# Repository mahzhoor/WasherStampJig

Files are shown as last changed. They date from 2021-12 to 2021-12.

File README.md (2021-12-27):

# WasherStampJig
DYI Printable 3D Template for Stamping Metal Washers - Cheap and secure Cold Storage for backing up your passwords and cryptocurrency seeds

v. 1.1

## The idea

To backup your sensitive data – stamp them on metal washers.  
This printable jig will allow you to align any letter stamps on any washers neatly.

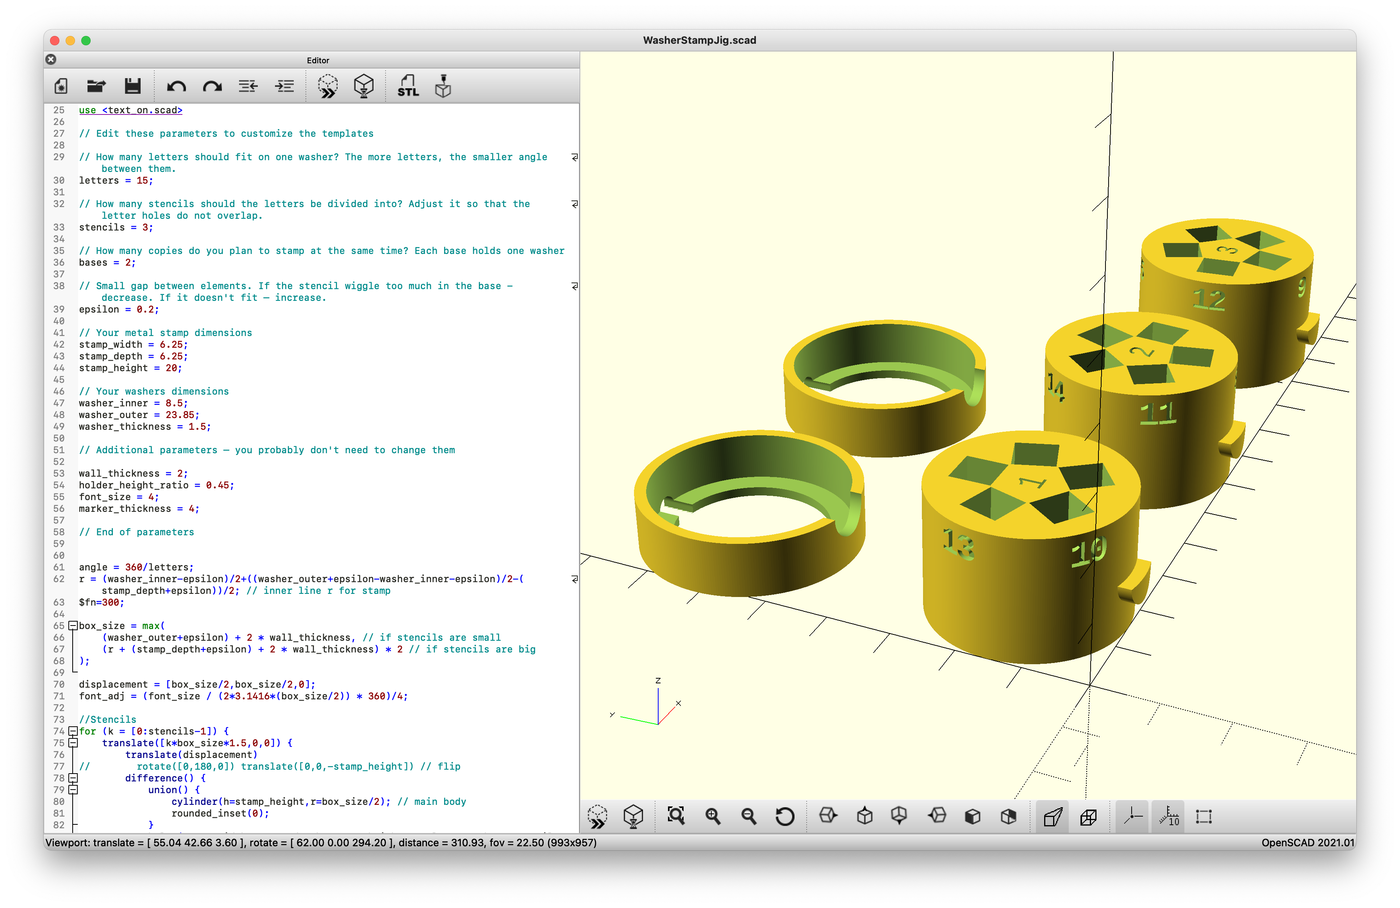
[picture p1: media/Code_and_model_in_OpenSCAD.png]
Code and 3D model in OpenSCAD software


Read more about the original idea of stamping washers: https://safu.ninja/  
Check out the [stress test/review](https://jlopp.github.io/metal-bitcoin-storage-reviews/reviews/safu-ninja/) and [comparison](https://jlopp.github.io/metal-bitcoin-storage-reviews/) to other solutions by Jameson Lopp.

## How to

### You'll need:
* Access to 3D printer 
* Metal stamps
* Metal washers
* Caliper
* Hammer
* Small anvil or any block/plate of metal
* Some tape - e.g. duct tape
* Marker pen

### Instructions:
1. Customize and generate the 3D template:
    1. Install [OpenSCAD](https://openscad.org/) software 
    1. Download and open the WasherStampJig.scad file
    1. Measure your washers and stamps
    1. Adjust the parameters to your needs – washer and stamp sizes, etc.
    1. Render the objects, generate STL file and print it in 3D
1. Prepare the base(s) – use two or more to create duplicates for backup purposes
    1. Put a piece of tape on flat surface
    1. Put the base on the tape so it stick from the bottom
    1. Put the washer in the hole in the base so it sticks to the tape
    1. Mark the washer side with a marker through the notch in the base side (so you can reposition it correctly in case it falls out in the middle of stamping)
1. Prepare the stencils:
    1. Write down all the words you wish to stamp in a table – put each word in a separate row, each letter in a separate column and number the columns
    1. Put the stamps for the first word in proper holes of the stencils - refer to the letter/column numbers in the table
1. Put the stencil in the base (so it sits on top of the washer) and hit the stamps with a hammer to stamp the letters – repeat for each stencil, base and word

## Why this?

### Customizability
You can easily adjust the jig to fit **any stamps** and any **any washers**. You can also adjust margins, height, font size etc.

### Usability and time savings
The design **saves you time** and makes it **easier** to create **multiple copies** of stamps.

Since the template for each stamp is broken into multiple stencils (to accomodate narrow angles between each stamp) – all of the letters of a word can be prepared in batch, at the same time.  
Then you can proceed to stamp all of them at once - on one or more washers (each taped to its own base).

This dramatically improves time needed to stamp multiple washers (in multiple copies) and reduces mistakes as compared to alternative solutions (which usually force you to stamp each letter separately).

Please see other implementations of the same idea to compare:
* [Blockmit Washer Jig](https://estudiobitcoin.com/fabrica-tu-billetera-fria-con-arandelas/)
* [Keytala Jig](https://www.hardwarewallet.it/en/keytala-jig/)

## Help needed

Contact me: mahzhoor@protonmail.com

## Support
If you have any **questions or suggestions** to the design or the (ugly!) code – please reach out to me at: Contact me: mahzhoor@protonmail.com

In case you've successfully used it – please **share** some **photos** and the **parameters** you used for the setup!

## Acknowledgements
* The code uses [text_on_OpenSCAD](https://github.com/brodykenrick/text_on_OpenSCAD) – library by [Brody Kenrick](https://github.com/brodykenrick) used for generating letters in OpenSCAD

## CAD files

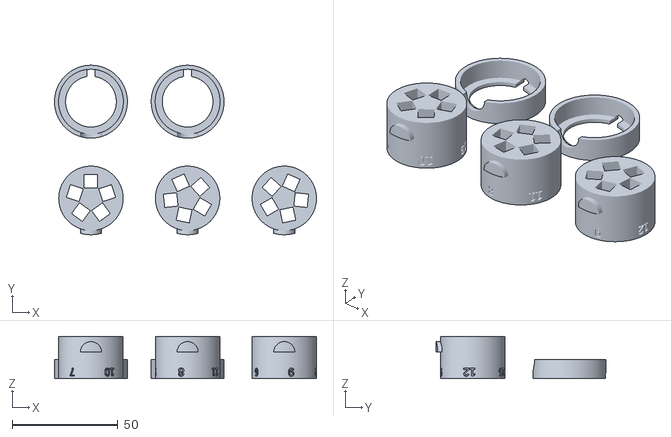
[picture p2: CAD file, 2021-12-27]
WasherStampJig_example.stl
123.7 x 80.1 x 20.0

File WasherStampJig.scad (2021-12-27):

/*
This is WasherStampJig by mahzhoor <mahzhoor@protonmail.com>
See https://github.com/mahzhoor/WasherStampJig for details

This program is free software: you can redistribute it and/or modify
it under the terms of the GNU General Public License as published by
the Free Software Foundation, either version 3 of the License, or
(at your option) any later version.

This program is distributed in the hope that it will be useful,
but WITHOUT ANY WARRANTY; without even the implied warranty of
MERCHANTABILITY or FITNESS FOR A PARTICULAR PURPOSE.  See the
GNU General Public License for more details.

You should have received a copy of the GNU General Public License
along with this program.  If not, see <https://www.gnu.org/licenses/>.

-

The following code requires text_on_OpenSCAD library (by Brody Kenrick) which is licensed LGPLv2.1.
See https://github.com/brodykenrick/text_on_OpenSCAD for details

*/

// v. 1.1

// Edit these parameters to customize the templates

/* Layout */

/* How many letters should fit on one washer? The more letters, the smaller angle between them. */
letters = 15;

/* How many stencils should the letters be divided into? Adjust it so that the letter holes do not overlap. */
stencils = 3;

/* How many copies do you plan to stamp at the same time? Each base holds one washer */
bases = 2;

/* Small gap between elements. If the stencil wiggle too much in the base - decrease. If it doesn't fit � increase. */
epsilon = 0.1;

/* Your metal stamps dimensions */
stamp_width = 6.25;
stamp_depth = 6.25;
stamp_height = 20;

/* Your washer dimensions */
washer_inner = 8.5;
washer_outer = 23.85;
washer_thickness = 1.5;

/* Additional parameters */
// You probably don't need to change them

wall_thickness = 2;
holder_height_ratio = 0.45;
font_size = 4;
marker_thickness = 4;

// End of parameters

/* [Hidden] */

angle = 360/letters;
r = (washer_inner-epsilon)/2+((washer_outer+epsilon-washer_inner-epsilon)/2-(stamp_depth+epsilon))/2; // inner line r for stamp
$fn=300;

box_size = max(
    (washer_outer+epsilon) + 2 * wall_thickness, // if stencils are small
    (r + (stamp_depth+epsilon) + 2 * wall_thickness) * 2 // if stencils are big
);

displacement = [box_size/2,box_size/2,0];
font_adj = (font_size / (2*3.1416*(box_size/2)) * 360)/4;

//Stencils
for (k = [0:stencils-1]) {
    translate([k*box_size*1.5,0,0]) {
        translate(displacement)
        rotate([0,180,0]) translate([0,0,-stamp_height]) // flip
        difference() {
            union() {
                cylinder(h=stamp_height,r=box_size/2); // main body
                translate([0,0,-washer_thickness]) rounded_inset(0);
            }
            holes(stamp_width, stamp_depth, stamp_height, r, letters, k+1, stencils); // holes
        }
    }

}

//Bases
for (m = [0:bases-1]) {
    translate([m*box_size*1.5+box_size/2,box_size*2,0])
    difference() {
        cylinder(h=stamp_height*holder_height_ratio,r=box_size/2+wall_thickness); // outer body
        translate([0,0,washer_thickness]) cylinder(h=stamp_height,r=box_size/2+epsilon); // inner body
        translate([0,0,-epsilon]) cylinder(h=washer_thickness+2*epsilon,d=washer_outer+epsilon); // washer
        union() { // marker hole
            translate([-marker_thickness/2,0,0]) cube([marker_thickness,box_size,washer_thickness/2+epsilon]);
            translate([0,0,washer_thickness/2+epsilon]) rotate([0,0,180]) rotate([90,0,0]) cylinder(r=marker_thickness/2, h=box_size);
        }
        rounded_inset(epsilon);
        
    } // difference
} // for

module rounded_inset(eps) {
    //eps is additional epsilon for spacing of the hole
    translate([0,3*epsilon,0])
    intersection() {
        difference() {
            cylinder(h=stamp_height*holder_height_ratio+eps,r=box_size/2+wall_thickness+3*epsilon+eps); // outer body
            translate([0,0,washer_thickness]) cylinder(h=stamp_height,r=box_size/2+epsilon/2-eps); // inner body with epsilon
        }
        translate([0,-box_size/2+wall_thickness/2+epsilon/4,stamp_height*holder_height_ratio-eps])
        rotate([90,0,0])
        cylinder(h=2*wall_thickness+eps,r=2.5*wall_thickness+eps);                
    }
}


module holes(width, depth, height, r, letters_count, stencil_nb, stencils) {
    
    //Top number
    text_on_cube(str(stencil_nb),cube_size=[box_size,box_size,height*2],face="top");


    for (i = [0:1:letters_count]){
        if (
            (i+1-stencil_nb)%stencils == 0 && // divisible per stencil_nb
            i*angle <= stencil_nb*angle+360-stencils*angle // last not in first
        ) {
            //Stamp hole
            rotate(i*-angle){
                translate([
                    -(stamp_width+epsilon)/2, r, -epsilon])
                cube([(stamp_width+epsilon), stamp_depth+epsilon, stamp_height+epsilon*2]);
               
            }
            //Number
            text_on_cylinder(str(i+1),font="RobotoMono:style=Bold",size=font_size,locn_vec=[0,0,height-font_size/2-wall_thickness/2],r=box_size/2,h=height,spacing=0.85,cylinder_center=true,eastwest=(-angle*i)-180+font_adj,extrusion_height=wall_thickness);
            
        }
    }

}


// The following code is part of the text_on_OpenSCAD library (by Brody Kenrick) which is licensed LGPLv2.1.
// See https://github.com/brodykenrick/text_on_OpenSCAD for details

// text_on.scad

/*  text on ....
    This is a rework of version 3 of write.scad to use the new OpenSCAD internal text() primitive.
    All credit to Harlan Martin (harlan@sutlog.com) for his great effort on the original.
    Great thanks to t-paul (and the OpenSCAD dev team) on adding the new text() primitive.
*/


/*
The arguments to be provided for each function are explictly in the modules.

All modules take close to all the arguments to text() [Not all features are supported in all text_on_object() modules though -- try them out warnings will be given if it is not supported]

text() params:
t
size
spacing
font
direction -- ltr, ttb, btt or rtl
language
script
halign -- left, right or center
valign -- baseline, bottom, top or center

All modules also take the additional arguments:
extrusion_height = depth of the letter, i.e. how far it sits proud
rotate
center //center the text at the location it is being written (NOT that the object is centered)

ALL faux-objects that the text is applied to have center=true
TODO: object_center=true/false (already done for cylinder)

The above arguemnts can be seen in text_extrude() as all modules call that module evetually (often multiple times).

locn_vector -- Where the faux-object has been translated to. TODO: Rename object to translate_vector?

Additional arguments for text_on_cube():

Additional arguments for text_on_cylinder():

Additional arguments for text_on_circle():

Additional arguments for text_on_sphere():


*/

// These control the default values for text_extrude(), text_on_sphere(), text_on_cube(), text_on_cylinder(), text_on_circle()
// if the arguments are not included in the call to the module.

// Defaults
// Defaults for all modules
default_t = "text_on";
default_size = 4; // TODO - Can we make this 10?? To match internal size? There is an underlying value in text() -- This masks that.
default_font = "Liberation Mono";
default_spacing = 1; // Spacing between characters. There is an underlying value in text() -- This masks that. We try and match it here.
default_rotate = 0; // text rotation (clockwise)
default_center = true; //Text-centering
default_scale = [1,1,1];
default_extrusion_height = 2; //mm letter extrusion height
default_buffer_width = 0; //mm of buffer (thickening in all directions) to add to each letter

//Defaults for Cube
default_cube_face = "front"; // default face (top,bottom,left,right,back,front)
default_sphere_rounded = false; // default for rounded letters on text_on_sphere
default_cube_updown = 0; // mm up (-down) from center on face of cube
default_cube_rightleft = 0; // mm right(-left) from center on face of cube

//Defaults for Sphere
default_sphere_northsouth = 0;
default_sphere_eastwest = 0;
default_sphere_spin = 0; // TODO:Different to rotate? or up/down. Better name?

//Defaults for Cylinder (including circle as it is on top/bottom)
default_circle_middle = 0; // (mm toward middle of circle)
default_circle_ccw = false; // write on top or bottom in a ccw direction
default_circle_eastwest = 0;
default_cylinder_face = "side";
default_cylinder_updown = 0;

// Internal values - don't play with these :)
// This is much more accurate than the PI constant internal to Openscad.
internal_pi = 3.1415926535897932384626433832795028841971693993751058209;
internal_pi2 = internal_pi * 2;

// Internal values - You might want to play with these if you are using a proportional font
internal_space_fudge = 0.80; // Fudge for working out lengths (widths) of strings

debug = true;
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

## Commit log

2021-12-16 First version
    [WasherStampJig.scad, WasherStampJig_example.stl, text_on.scad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]
2021-12-16 Added text_on_OpenSCAD libraries to the main file - to enable Cutomizer on Thingiverse
    [WasherStampJig.scad, text_on.scad, text_on_cylinder.scad]
2021-12-16 Customizer fixes
    [WasherStampJig.scad]
2021-12-27 Alignmnet fixes
    [WasherStampJig.scad, WasherStampJig_example.stl]
